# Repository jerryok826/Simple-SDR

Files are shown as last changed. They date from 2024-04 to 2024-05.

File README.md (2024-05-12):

# Simple-SDR
Simple-SDR is a basic Software Defined Receiver for experimentation

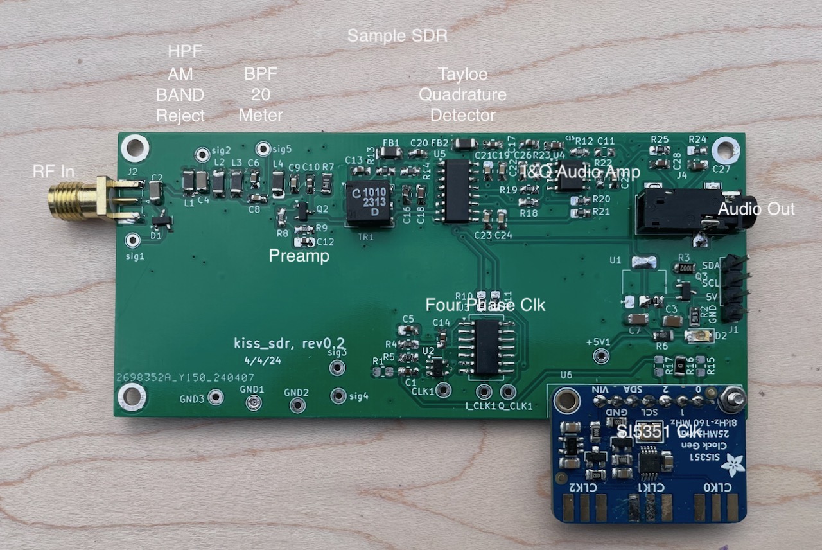
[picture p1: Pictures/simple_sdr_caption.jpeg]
Robot_Front


## Project Description
The SDR board has the basic components of a 20 meter Ham band SDR receiver. The sections are:
1. A 1.5MHz HPF to reject Broadcast band signals.
2. A 20 meter Ham band BPF.
3. RF Preamp.
4. A Tayloe quadrature detector
5. I and Q clock generator.
6. SI5351 programmable clock
7. I&Q Audio amps

Other SDR projects of interest:

https://community.element14.com/challenges-projects/project14/radiocontrol/b/blog/posts/software-defined-radio-sdr-experiment-board

https://github.com/ukagit/sdr_kiss

https://github.com/do7jbh/SSR-2

https://github.com/DD4WH/Teensy-ConvolutionSDR.

https://github.com/Dizzerin/Software-Defined-Radio

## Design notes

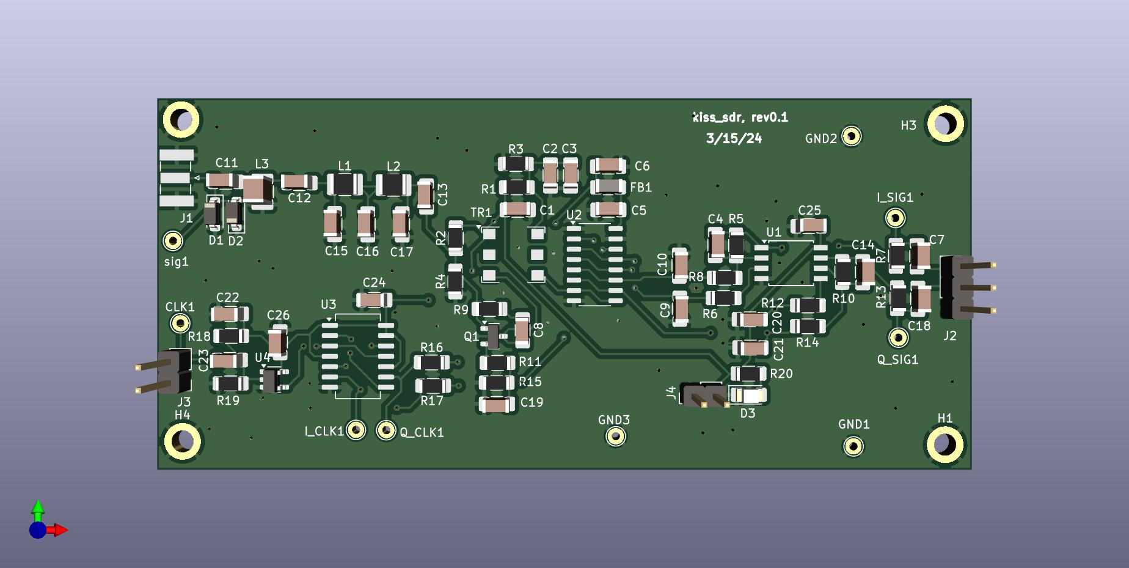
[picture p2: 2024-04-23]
Hardware/kiss_sdr_r1/kiss_sdr_r1.jpg

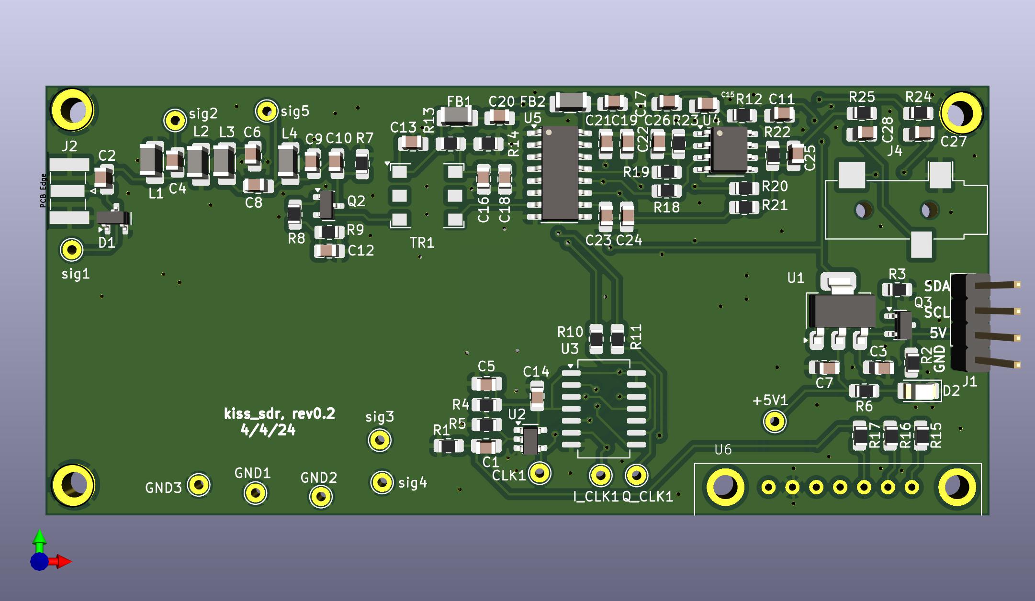
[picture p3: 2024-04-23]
Hardware/kiss_sdr_r2/kiss_sdr_r2.jpg

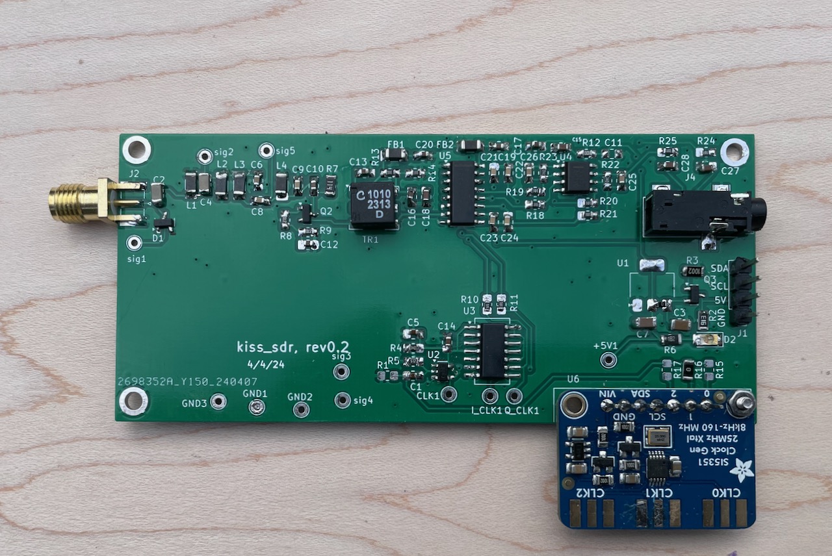
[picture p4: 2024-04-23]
Pictures/simple_sdr.jpeg

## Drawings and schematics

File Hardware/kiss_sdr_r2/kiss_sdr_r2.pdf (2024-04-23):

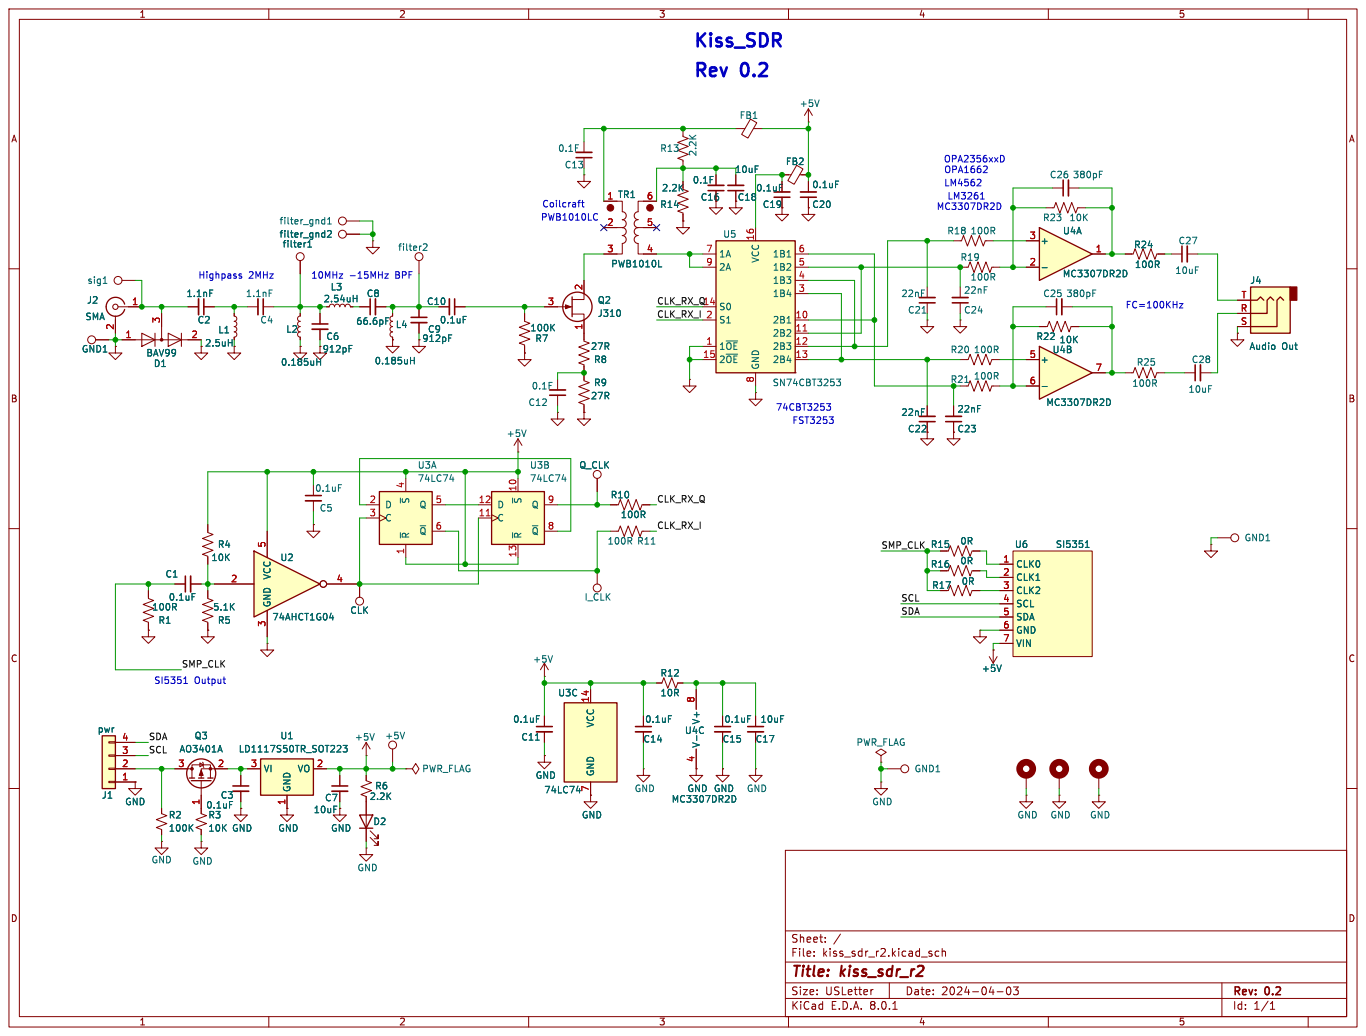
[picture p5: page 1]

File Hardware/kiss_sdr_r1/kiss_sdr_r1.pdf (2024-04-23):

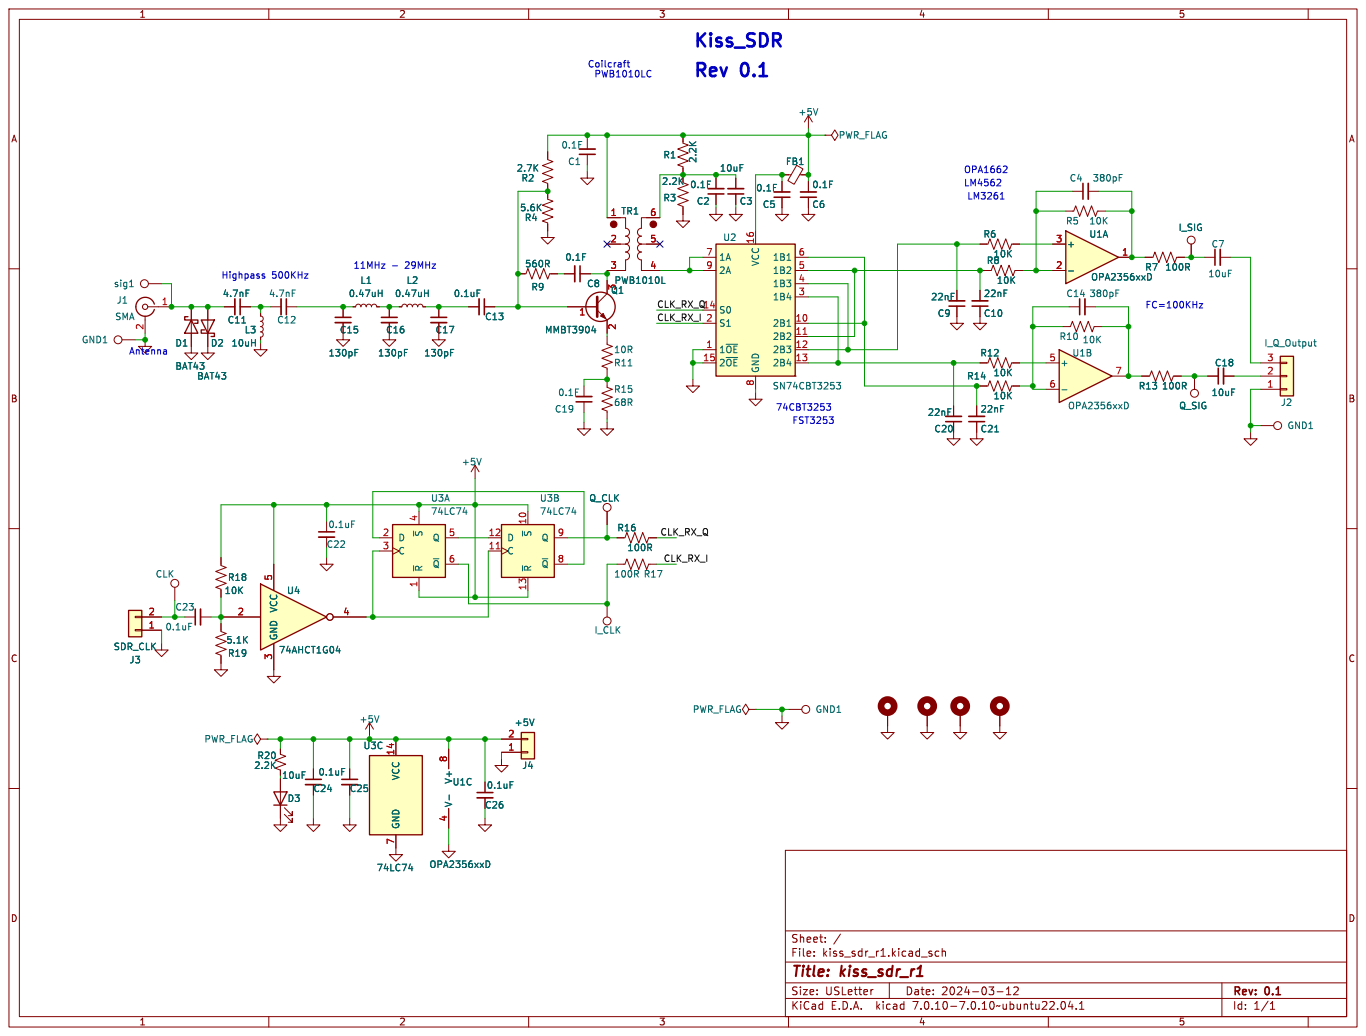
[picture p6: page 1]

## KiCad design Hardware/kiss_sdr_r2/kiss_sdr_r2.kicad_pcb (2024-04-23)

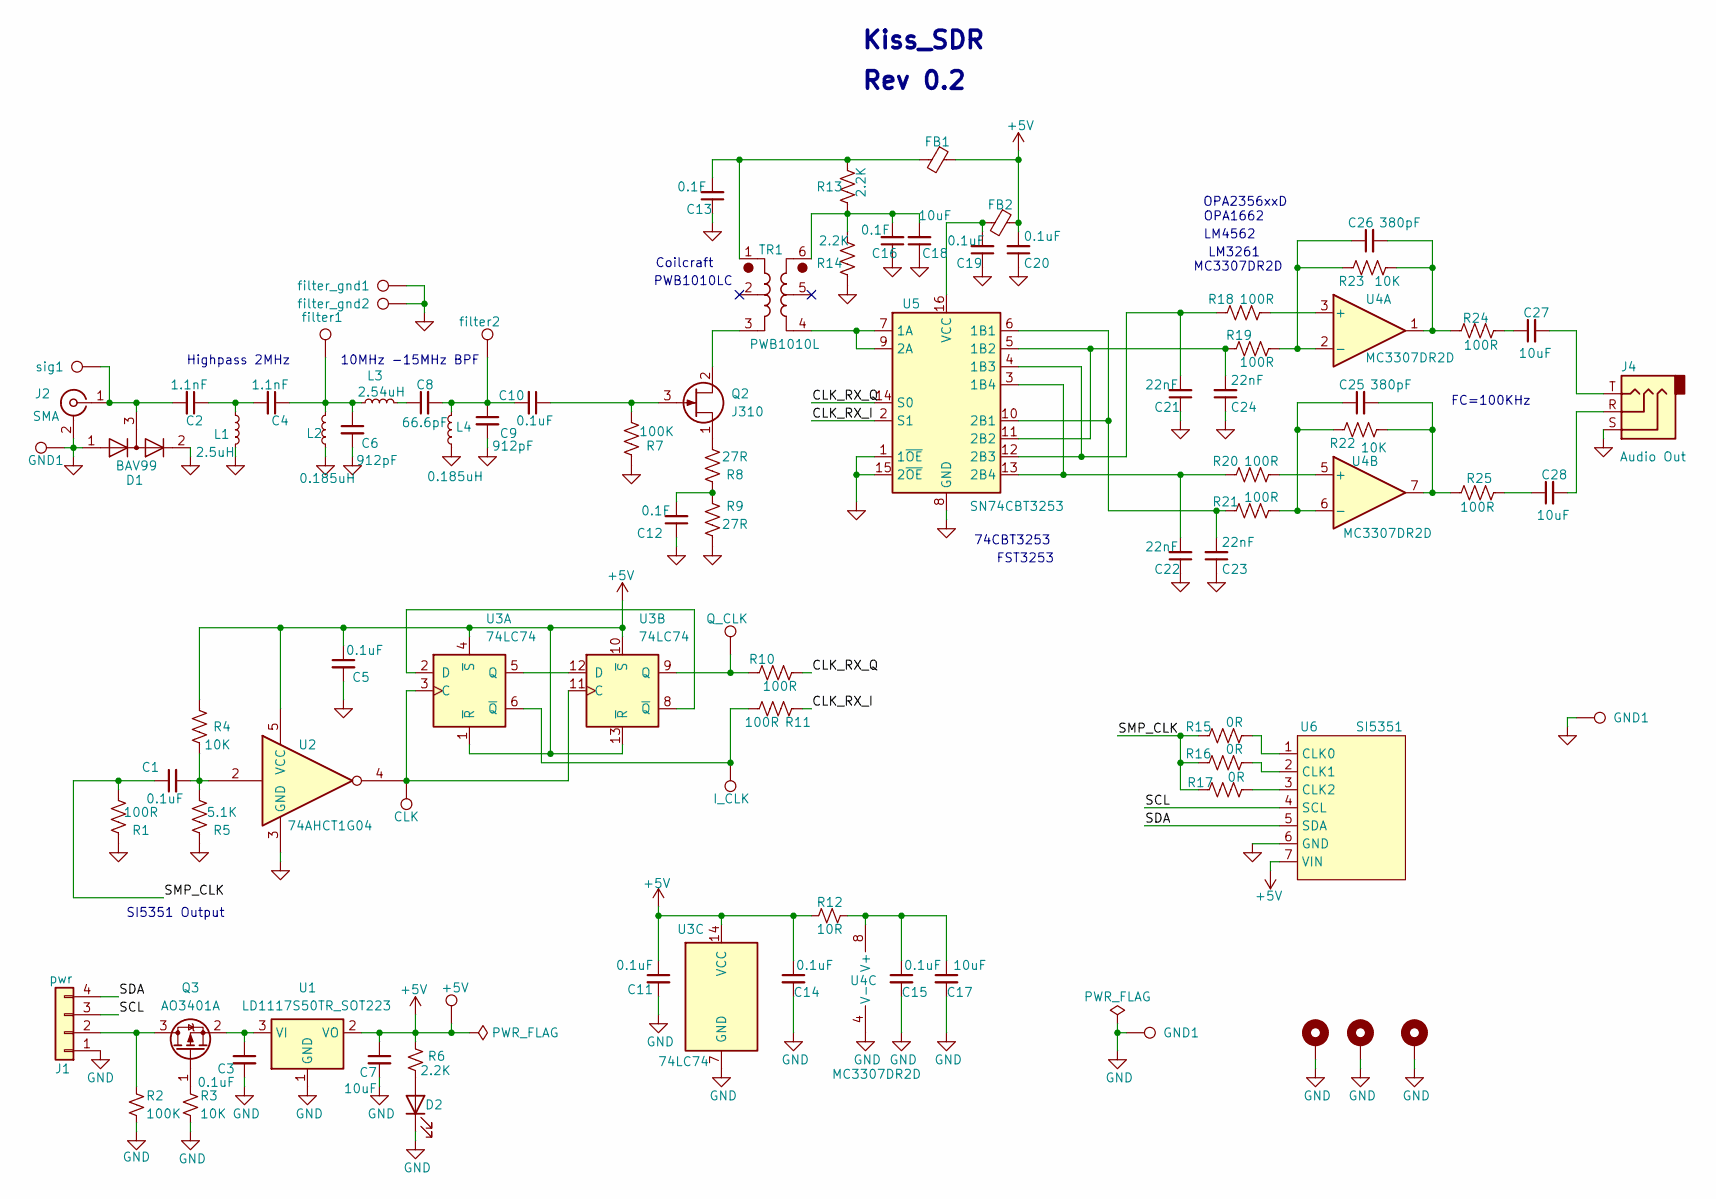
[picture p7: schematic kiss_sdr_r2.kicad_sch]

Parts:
+5V1: +5V; TestPoint_THTPad_D2.0mm_Drill1.0mm
C1, C3, C5, C10, C11, C14, C15, C19, C20: 0.1uF; C_0805_2012Metric_Pad1.18x1.45mm_HandSolder
C2, C4: 1.1nF; C_0805_2012Metric_Pad1.18x1.45mm_HandSolder
C6, C9: 912pF; C_0805_2012Metric_Pad1.18x1.45mm_HandSolder
C7, C17, C18, C27, C28: 10uF; C_0805_2012Metric_Pad1.18x1.45mm_HandSolder
C8: 66.6pF; C_0805_2012Metric_Pad1.18x1.45mm_HandSolder
C12, C13, C16: 0.1F; C_0805_2012Metric_Pad1.18x1.45mm_HandSolder
C21, C22, C23, C24: 22nF; C_0805_2012Metric_Pad1.18x1.45mm_HandSolder
C25, C26: 380pF; C_0805_2012Metric_Pad1.18x1.45mm_HandSolder
CLK1: CLK; TestPoint_THTPad_D2.0mm_Drill1.0mm
D1: BAV99; SOT-23
D2: OC_Fault; LED_1206_3216Metric_Pad1.42x1.75mm_HandSolder
FB1, FB2: FerriteBead, 6A 1 9mΩ 33Ω@100MHz ±25% 1206 Ferrit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; L_1206_3216Metric_Pad1.42x1.75mm_HandSolder
GND1, GND2, GND3: GND1; TestPoint_THTPad_D2.0mm_Drill1.0mm
H2, H3, H4: MountingHole_Pad; MountingHole_2.7mm_M2.5_ISO14580_Pad
I_CLK1: I_CLK; TestPoint_THTPad_D2.0mm_Drill1.0mm
J1: pwr; PinHeader_1x04_P2.54mm_Vertical
J2: SMA; SMA_Samtec_SMA-J-P-X-ST-EM1_EdgeMount
J4: Audio Out; Jack_3.5mm_CUI_SJ-3523-SMT_Horizontal
L1: 2.5uH; L_1206_3216Metric_Pad1.22x1.90mm_HandSolder
L2, L4: 0.185uH; L_1206_3216Metric_Pad1.22x1.90mm_HandSolder
L3: 2.54uH; L_1206_3216Metric_Pad1.22x1.90mm_HandSolder
Q2: J310; SOT-23
Q3: AO3401A; SOT-23
Q_CLK1: Q_CLK; TestPoint_THTPad_D2.0mm_Drill1.0mm
R1, R10, R11, R18, R19, R20, R21, R24, R25: 100R; R_0805_2012Metric_Pad1.20x1.40mm_HandSolder
R2, R7: 100K; R_0805_2012Metric_Pad1.20x1.40mm_HandSolder
R3, R4, R22, R23: 10K; R_0805_2012Metric_Pad1.20x1.40mm_HandSolder
R5: 5.1K; R_0805_2012Metric_Pad1.20x1.40mm_HandSolder
R6, R13, R14: 2.2K; R_0805_2012Metric_Pad1.20x1.40mm_HandSolder
R8, R9: 27R; R_0805_2012Metric_Pad1.20x1.40mm_HandSolder
R12: 10R; R_0805_2012Metric_Pad1.20x1.40mm_HandSolder
R15, R16, R17: 0R; R_0805_2012Metric_Pad1.20x1.40mm_HandSolder
TR1: PWB1010L; Transformer_Coilcraft_PWB1010
U1: LD1117S50TR_SOT223; SOT-223-3_TabPin2
U2: 74AHCT1G04; SOT-23-5
U3: 74LC74; SO-14_5.3x10.2mm_P1.27mm
U4: MC3307DR2D; SOIC-8_3.9x4.9mm_P1.27mm
U5: SN74CBT3253; SO-16_3.9x9.9mm_P1.27mm
U6: SI5351; SI5351_Brd_fp
sig1: sig1; TestPoint_THTPad_D2.0mm_Drill1.0mm
sig2: filter1; TestPoint_THTPad_D2.0mm_Drill1.0mm
sig3: filter_gnd1; TestPoint_THTPad_D2.0mm_Drill1.0mm
sig4: filter_gnd2; TestPoint_THTPad_D2.0mm_Drill1.0mm
sig5: filter2; TestPoint_THTPad_D2.0mm_Drill1.0mm

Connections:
+5V: +5V1.1, C5.1, C7.1, C11.1, C14.1, C20.2, FB1.1, FB2.1, R4.2, R6.2, R12.2, U1.2 (VO), U2.5 (VCC), U3.1 (~R), U3.4 (~S), U3.10 (~S), U3.13 (~R), U3.14 (VCC), U6.7 (VIN)
/CLK_RX_I: R11.2, U5.2 (S1)
/CLK_RX_Q: R10.2, U5.14 (S0)
/SCL: J1.3, U6.4 (SCL)
/SDA: J1.4, U6.5 (SDA)
/SMP_CLK: C1.1, R1.2, R15.1, R16.1, R17.1
GND: C3.2, C5.2, C6.2, C7.2, C9.2, C11.2, C12.1, C13.1, C14.2, C15.2, C16.1, C17.2, C18.1, C19.1, C20.1, C21.1, C22.1, C23.1, C24.1, D1.1 (K), D1.2 (A), D2.1 (K), GND1.1, GND2.1, GND3.1, H2.1, H3.1, H4.1, J1.1, J2.2 (Ext), J4.S, L1.2, L2.1, L4.1, R1.1, R2.2, R3.2, R5.1, R7.1, R9.1, R14.1, U1.1 (GND), U2.3 (GND), U3.7 (GND), U4.4 (V-), U5.1 (1~OE), U5.8 (GND), U5.15 (2~OE), U6.6 (GND), sig3.1, sig4.1
unnamed: C1.2, R4.1, R5.2, U2.2
unnamed: C2.1, C4.2, L1.1
unnamed: C4.1, C6.1, L2.2, L3.1, sig2.1
unnamed: C8.1, L3.2
unnamed: C8.2, C9.1, C10.2, L4.2, sig5.1
unnamed: C12.2, R8.1, R9.2
unnamed: C13.2, FB1.2, R13.2, TR1.1
unnamed: C16.2, C18.2, R13.1, R14.2, TR1.6
unnamed: C25.2, R22.2, R25.1, U4.7
unnamed: C26.2, R23.2, R24.1, U4.1
unnamed: C27.1, R24.2
unnamed: C27.2, J4.T
unnamed: C28.1, R25.2
unnamed: C28.2, J4.R
unnamed: D2.2 (A), R6.1
unnamed: J1.2, Q3.3 (D), R2.1
unnamed: C2.2, D1.3 (K), J2.1 (In), sig1.1
unnamed: Q2.2 (D), TR1.3
unnamed: C10.1, Q2.3 (G), R7.2
unnamed: Q2.1 (S), R8.2
unnamed: Q3.1 (G), R3.1
unnamed: C3.1, Q3.2 (S), U1.3 (VI)
unnamed: CLK1.1, U2.4, U3.3 (C), U3.11 (C)
unnamed: U3.2 (D), U3.8 (~Q)
unnamed: U3.5 (Q), U3.12 (D)
unnamed: I_CLK1.1, R11.1, U3.6 (~Q)
unnamed: Q_CLK1.1, R10.1, U3.9 (Q)
unnamed: R18.2, U4.3 (+)
unnamed: C26.1, R19.2, R23.1, U4.2 (-)
unnamed: R20.2, U4.5 (+)
unnamed: C25.1, R21.2, R22.1, U4.6 (-)
unnamed: C15.1, C17.1, R12.1, U4.8 (V+)
unnamed: TR1.4, U5.7 (1A), U5.9 (2A)
unnamed: C23.2, R21.1, U5.6 (1B1), U5.10 (2B1)
unnamed: C24.2, R19.1, U5.5 (1B2), U5.11 (2B2)
unnamed: C21.2, R18.1, U5.4 (1B3), U5.12 (2B3)
unnamed: C22.2, R20.1, U5.3 (1B4), U5.13 (2B4)
unnamed: C19.2, FB2.2, U5.16 (VCC)
unnamed: R15.2, U6.1 (CLK0)
unnamed: R16.2, U6.2 (CLK1)
unnamed: R17.2, U6.3 (CLK2)

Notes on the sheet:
10MHz -15MHz BPF
Highpass 2MHz
Coilcraft
Kiss_SDR
OPA2356xxD
FC=100KHz
MC3307DR2D
Rev 0.2
LM3261
OPA1662
SI5351 Output
74CBT3253
FST3253
LM4562
PWB1010LC

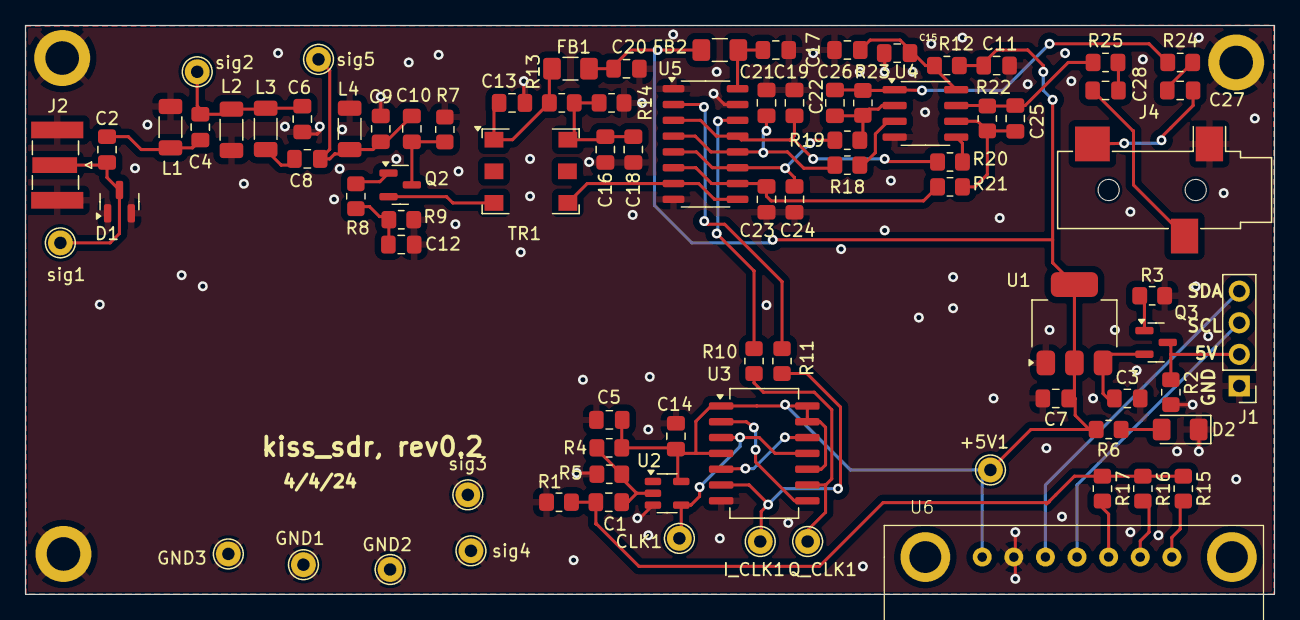
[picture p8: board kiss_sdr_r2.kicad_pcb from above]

Board: 2 copper layers, 100.4 x 45.7 mm, 88 parts (0 on the bottom side), 48 nets.

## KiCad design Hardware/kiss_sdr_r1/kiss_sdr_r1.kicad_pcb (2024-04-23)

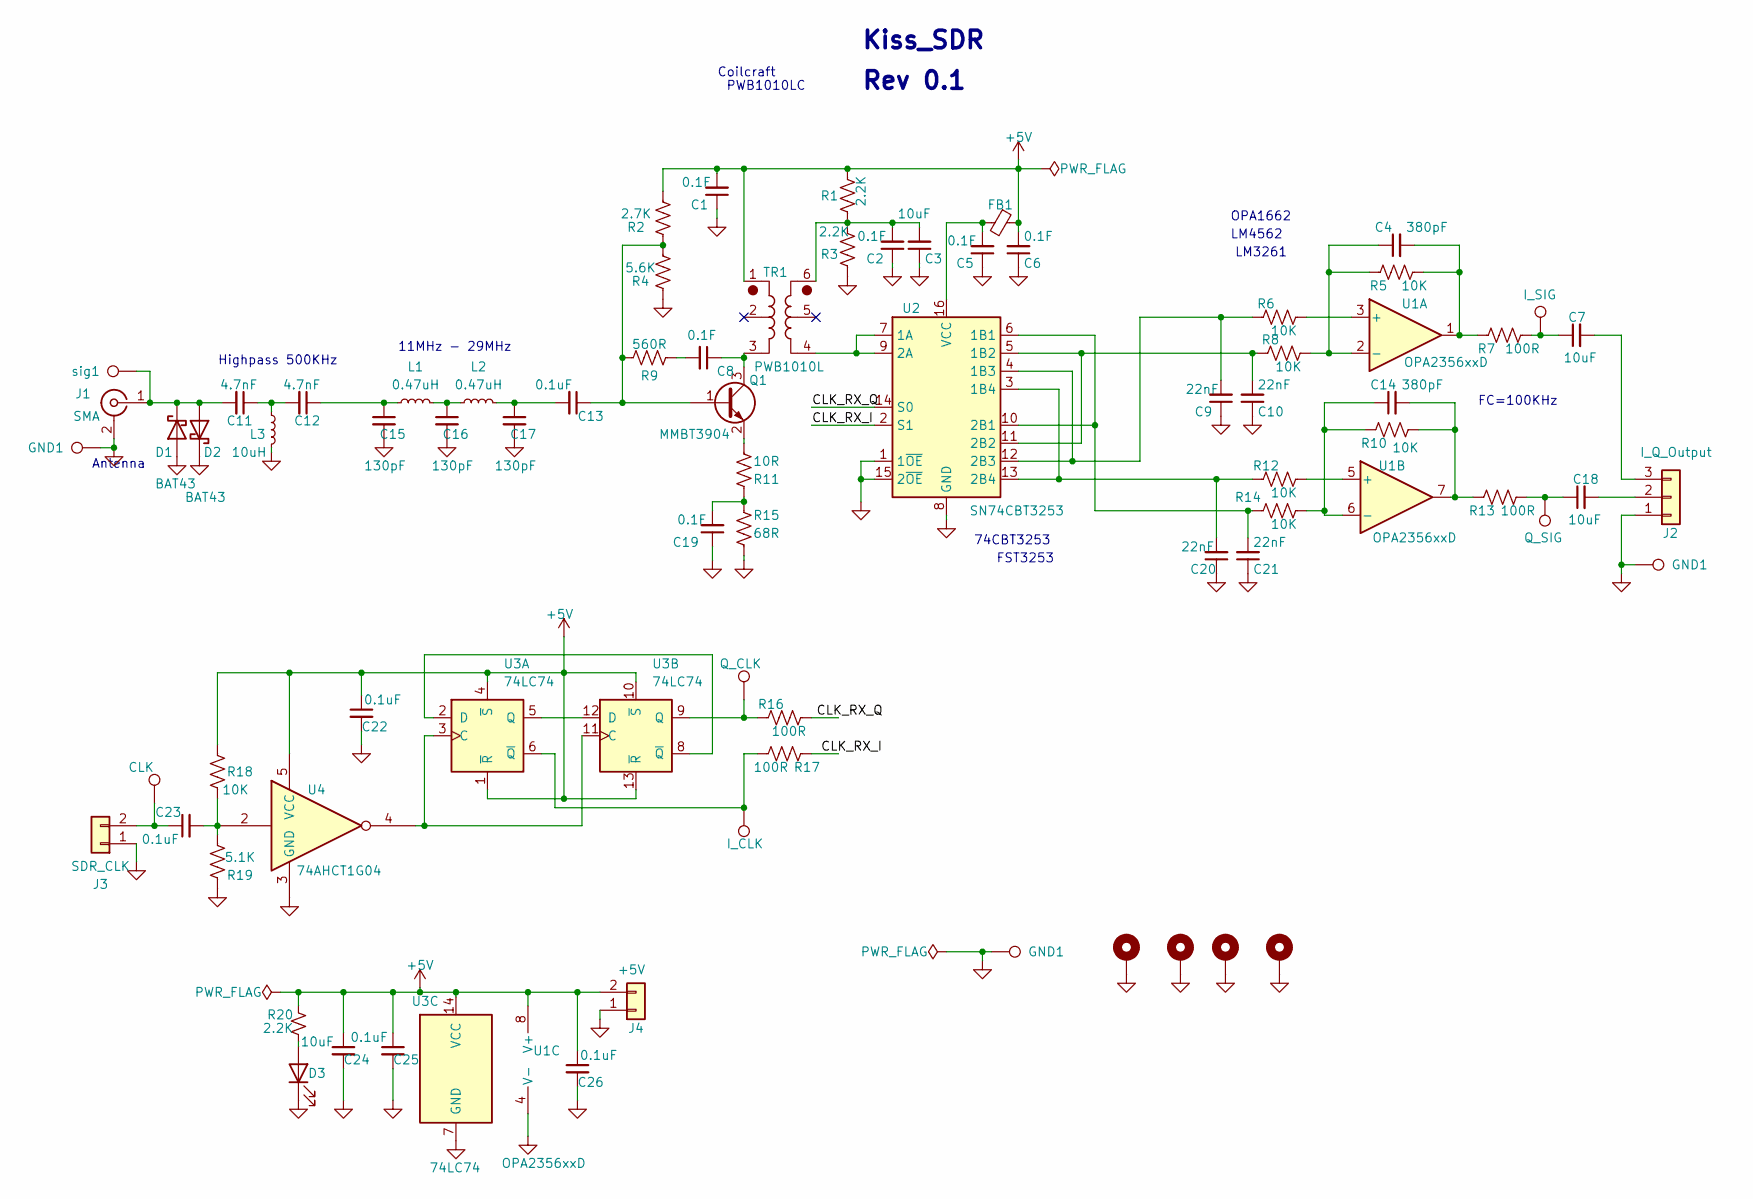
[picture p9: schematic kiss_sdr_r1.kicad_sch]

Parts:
C1, C2, C5, C6, C8, C19: 0.1F; C_1206_3216Metric_Pad1.33x1.80mm_HandSolder
C3, C7, C18, C24: 10uF; C_1206_3216Metric_Pad1.33x1.80mm_HandSolder
C4, C14: 380pF; C_1206_3216Metric_Pad1.33x1.80mm_HandSolder
C9, C10, C20, C21: 22nF; C_1206_3216Metric_Pad1.33x1.80mm_HandSolder
C11, C12: 4.7nF; C_1206_3216Metric_Pad1.33x1.80mm_HandSolder
C13, C22, C23, C25, C26: 0.1uF; C_1206_3216Metric_Pad1.33x1.80mm_HandSolder
C15, C16, C17: 130pF; C_1206_3216Metric_Pad1.33x1.80mm_HandSolder
CLK1: CLK; TestPoint_THTPad_D2.0mm_Drill1.0mm
D1, D2: BAT43; D_SOD-123
D3: OC_Fault; LED_1206_3216Metric_Pad1.42x1.75mm_HandSolder
FB1: FerriteBead, 6A 1 9mΩ 33Ω@100MHz ±25% 1206 Ferrit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; L_1206_3216Metric_Pad1.42x1.75mm_HandSolder
GND1, GND2, GND3: GND1; TestPoint_THTPad_D2.0mm_Drill1.0mm
H1, H2, H3, H4: MountingHole_Pad; MountingHole_2.7mm_M2.5_ISO14580_Pad
I_CLK1: I_CLK; TestPoint_THTPad_D2.0mm_Drill1.0mm
I_SIG1: I_SIG; TestPoint_THTPad_D2.0mm_Drill1.0mm
J1: SMA; SMA_Samtec_SMA-J-P-X-ST-EM1_EdgeMount
J2: I_Q_Output; PinHeader_1x03_P2.54mm_Vertical
J3: SDR_CLK; PinHeader_1x02_P2.54mm_Vertical
J4: +5V; PinHeader_1x02_P2.54mm_Vertical
L1, L2: 0.47uH; R_1210_3225Metric_Pad1.30x2.65mm_HandSolder
L3: 10uH; C_1210_3225Metric_Pad1.33x2.70mm_HandSolder
Q1: MMBT3904; SOT-23
Q_CLK1: Q_CLK; TestPoint_THTPad_D2.0mm_Drill1.0mm
Q_SIG1: Q_SIG; TestPoint_THTPad_D2.0mm_Drill1.0mm
R1, R3, R20: 2.2K; R_1206_3216Metric_Pad1.30x1.75mm_HandSolder
R2: 2.7K; R_1206_3216Metric_Pad1.30x1.75mm_HandSolder
R4: 5.6K; R_1206_3216Metric_Pad1.30x1.75mm_HandSolder
R5, R6, R8, R10, R12, R14, R18: 10K; R_1206_3216Metric_Pad1.30x1.75mm_HandSolder
R7, R13, R16, R17: 100R; R_1206_3216Metric_Pad1.30x1.75mm_HandSolder
R9: 560R; R_1206_3216Metric_Pad1.30x1.75mm_HandSolder
R11: 10R; R_1206_3216Metric_Pad1.30x1.75mm_HandSolder
R15: 68R; R_1206_3216Metric_Pad1.30x1.75mm_HandSolder
R19: 5.1K; R_1206_3216Metric_Pad1.30x1.75mm_HandSolder
TR1: PWB1010L; Transformer_Coilcraft_PWB1010
U1: OPA2356xxD
U2: SN74CBT3253; SO-16_3.9x9.9mm_P1.27mm
U3: 74LC74; SO-14_5.3x10.2mm_P1.27mm
U4: 74AHCT1G04; SOT-23-5
sig1: sig1; TestPoint_THTPad_D2.0mm_Drill1.0mm

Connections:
+5V: C1.2, C6.2, C22.1, C24.1, C25.1, C26.1, FB1.1, J4.2, R1.2, R2.2, R18.2, R20.2, TR1.1, U1.8 (V+), U3.1 (~R), U3.4 (~S), U3.10 (~S), U3.13 (~R), U3.14 (VCC), U4.5 (VCC)
/CLK_RX_I: R17.2, U2.2 (S1)
/CLK_RX_Q: R16.2, U2.14 (S0)
GND: C1.1, C2.1, C3.1, C5.1, C6.1, C9.1, C10.1, C15.2, C16.2, C17.2, C19.1, C20.1, C21.1, C22.2, C24.2, C25.2, C26.2, D1.2 (A), D2.1 (K), D3.1 (K), GND1.1, GND2.1, GND3.1, H1.1, H2.1, H3.1, H4.1, J1.2 (Ext), J2.1, J3.1, J4.1, L3.2, R3.1, R4.1, R15.1, R19.1, U1.4 (V-), U2.1 (1~OE), U2.8 (GND), U2.15 (2~OE), U3.7 (GND), U4.3 (GND)
unnamed: C2.2, C3.2, R1.1, R3.2, TR1.6
unnamed: C4.2, R5.2, R7.1, U1.1
unnamed: C7.1, I_SIG1.1, R7.2
unnamed: C8.2, R9.1
unnamed: C11.1, C12.2, L3.1
unnamed: C12.1, C15.1, L1.1
unnamed: C13.2, C17.1, L2.2
unnamed: C14.2, R10.2, R13.1, U1.7
unnamed: C16.1, L1.2, L2.1
unnamed: C18.1, Q_SIG1.1, R13.2
unnamed: C19.2, R11.1, R15.2
unnamed: C23.2, R18.1, R19.2, U4.2
unnamed: C11.2, D1.1 (K), D2.2 (A), J1.1 (In), sig1.1
unnamed: D3.2 (A), R20.1
unnamed: C18.2, J2.2
unnamed: C7.2, J2.3
unnamed: C23.1, CLK1.1, J3.2
unnamed: C13.1, Q1.1 (B), R2.1, R4.2, R9.2
unnamed: C8.1, Q1.3 (C), TR1.3
unnamed: Q1.2 (E), R11.2
unnamed: R6.2, U1.3 (+)
unnamed: C4.1, R5.1, R8.2, U1.2 (-)
unnamed: R12.2, U1.5 (+)
unnamed: C14.1, R10.1, R14.2, U1.6 (-)
unnamed: TR1.4, U2.7 (1A), U2.9 (2A)
unnamed: C21.2, R14.1, U2.6 (1B1), U2.10 (2B1)
unnamed: C10.2, R8.1, U2.5 (1B2), U2.11 (2B2)
unnamed: C9.2, R6.1, U2.4 (1B3), U2.12 (2B3)
unnamed: C20.2, R12.1, U2.3 (1B4), U2.13 (2B4)
unnamed: C5.2, FB1.2, U2.16 (VCC)
unnamed: U3.3 (C), U3.11 (C), U4.4
unnamed: U3.2 (D), U3.8 (~Q)
unnamed: U3.5 (Q), U3.12 (D)
unnamed: I_CLK1.1, R17.1, U3.6 (~Q)
unnamed: Q_CLK1.1, R16.1, U3.9 (Q)

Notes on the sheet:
11MHz - 29MHz
Highpass 500KHz
Coilcraft
Kiss_SDR
FC=100KHz
Antenna
Rev 0.1
LM3261
OPA1662
74CBT3253
FST3253
LM4562
PWB1010LC

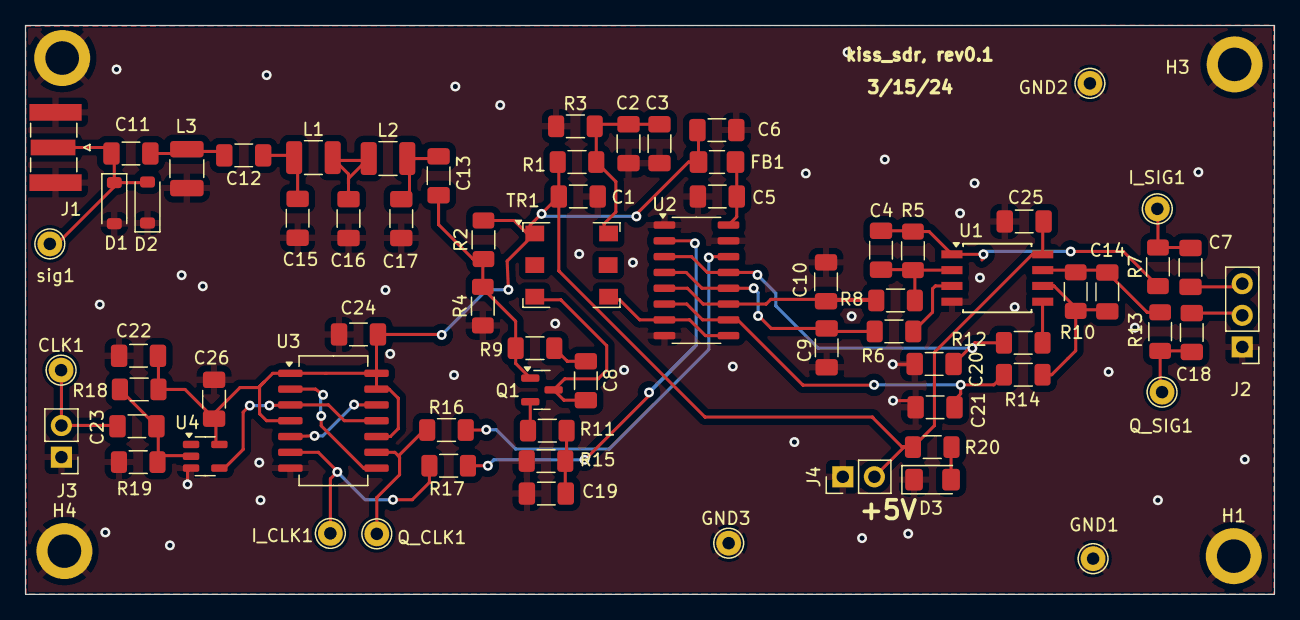
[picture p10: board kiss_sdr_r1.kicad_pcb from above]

Board: 2 copper layers, 100.4 x 45.7 mm, 76 parts (0 on the bottom side), 39 nets.

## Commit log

2024-04-23 add sdr files
    [kiss_sdr_r1-B_Cu.gbl, kiss_sdr_r1-B_Mask.gbs, kiss_sdr_r1-B_Paste.gbp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]
2024-04-23 update current files
    [kiss_sdr_r2-B_Cu.gbl, kiss_sdr_r2-B_Mask.gbs, kiss_sdr_r2-B_Paste.gbp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]
